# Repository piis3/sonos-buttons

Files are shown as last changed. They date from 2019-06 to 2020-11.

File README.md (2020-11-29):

This is a hobby project for controlling a sonos player using an ESP32 board and a button pad. I got the idea for the 
project while working in my garage and having gloves on or dirty hands and not wanting to mess with my phone to control the 
sonos player in there. Obviously the lazy thing would have been to get a voice assistant in there, but what fun is that?

I wanted something that I could place anywhere in the garage. Being able to run from battery (low power) and WiFi were 
important considerations. I was clearly looking for a fun project here, otherwise I probably would have gone with some 
AWS button concoction, or perhaps gone with one of the commercially available sonos remote control options.

So I wound up going with a handful of stuff from Sparkfun:
- [ESP32 Thing](https://www.sparkfun.com/products/13907)
- [2x2 Button Pad](https://www.sparkfun.com/products/9277)
- [Buttons](https://www.sparkfun.com/products/7836)
- [Buttons Bezel](https://www.sparkfun.com/products/8746)
- [Diodes](https://www.sparkfun.com/products/8588)

The ESP32 fit the bill for the project since it has a ridiculously low power draw when it's in sleep, has WiFi 
built in and the sparkfun board comes with a LIPO battery charger on it.

## Software
I had initially used the Sonos public control API, which goes through Sonos' servers to control your local sonos
player. After getting this all working I found the latency period to be less than ideal. Sonos also
had a multi day service outage while I was wrapping up work on that version. I settled on using the local network UPnP based 
API that the official sonos applications use. Much of the detail on this came from [SoCo](https://github.com/SoCo/SoCo), so 
thanks for that!

Since my hardware design has four buttons, the software supports four opertations:
- Play/Pause
- Next track
- Volume up
- Volume Down

If you want to use this project yourself, you'll need to first find the UID of the sonos player that you want to control. 
For this I recommend using the [SoCo](https://github.com/SoCo/SoCo) library. Once you've got it installed locally:

```
>>> import soco
>>> [zone.uid for zone in soco.discover() if zone.player_name == 'Garage']
['RINCON_XXXXXXXXXXXX']
```

Set the SONOS_UID constant in `sonos_buttons.cpp` to the sonos player UID you want to control and while you're there set the
SSID and PASSWORD macros to your WiFi credentials..

### Building

You'll need an ESP32 development environment setup: see [these instructions](https://docs.espressif.com/projects/esp-idf/en/v3.2.3/get-started/index.html) and you'll need the [ULP Toolchain](https://docs.espressif.com/projects/esp-idf/en/v3.2.3/api-guides/ulp.html#installing-the-toolchain) too. 
Because the esp-arduino module currently requires the v3.2 branch of esp-IDF, you'll need to stick with that version for compiling. 
It looks like the 4.0 branch completely changed how builds work so this project would likely need some updates too.

Once you have the environment setup, run `make menuconfig` and set the default serial port your ESP32 board appears as. This is under the "Serial flasher config" menu item. There's a ton of other options, but that's the only one you need to change.

To flash run `make flash` and then to see serial output run `make monitor`. This will build all of the FreeRTOS stuff too, which is a lot, so make's `-j` argument could be helpful here to use multiple processors.

### Implementation

Since power is a concern here, I wanted to make use of the deep sleep feature of the ESP32 SOC. This allows it to go into a
state that draws *micro*amps of current while still being able to respond to external stimuli. See [the ESP32 sleep docs](https://docs.espressif.com/projects/esp-idf/en/latest/api-reference/system/sleep_modes.html) for details on that.

After waking up from a deep sleep the ESP32 has to rejoin wifi, which usually takes a couple of seconds, so one of the hardest things
was to get it to remember what button was pressed to wake it up from deep sleep. I didn't have a lot of luck with the built-in 
touchpad, or GPIO (ext1) based wakeup solutions. The ext1 stuff kept going into sleep/wake loops, and the touchpad wakeups 
wouldn't report the correct GPIO input for the wakeup source. 

The ESP32 supports wakeup events from a Ultra Low Power (ULP) processor, which is a minimal extra processor that can run some limited code and can wakeup the main processor while
sharing memory with it. When this ULP processor is running and the main processor is in deep sleep, the board supposedly draws current in the 100 microamp
range, so it should still last a very long time on a 1000mah battery. An important point is that during deep sleep, most of main
memory is powered off.  When it wakes up it is effectively like a reboot but the so-called RTC memory is still active. The 
main program can store stuff in this memory (which is 16K I think) and the ULP processor can use an 8K subset of this
which is shared with the main program. 
There isn't a C compiler for the ULP processor, so that part has to be written in assembly with a rather limited 
[instruction set](https://docs.espressif.com/projects/esp-idf/en/latest/api-guides/ulp_instruction_set.html). The ULP program 
lifecycle is a little strange. It's intended to run periodically, woken up by a configurable timer internal to the SOC. In my
case I have it running every 100 milliseconds and it will check to see if any buttons are pressed. If it detects a button press
it will write the button that was pressed into the shared RTC memory and wakeup the main processor(s). If not, it will halt and be restarted by the timer.

On boot the main application does the following:
- Initialize the GPIO pins for controlling the button LEDs and button readers
- Start a FreeRTOS task for controlling the LEDs based on a global variable. This way it can handle keeping the LEDS operational while the CPU is blocked in IO. How cool is it that a tiny computer like this supports real multitasking?
- If we're not waking from sleep, do a cute blinky dance to show off
- If we are waking from sleep, check if the ULP program stashed a button press to be acted on in the first button input loop
- Join wifi and if that fails, do some angry blinking.
- Look in the [Preferences](https://github.com/espressif/arduino-esp32/tree/master/libraries/Preferences) stored on the SOC's flash for the Sonos player's IP address 
- If we don't know the IP address, perform Sonos discovery to find it
- Enter a loop to check for button inputs.
- If a button input occurs, light up the button LED for the duration of the association operation for user feedback and perform that operation.
- After roughly 30 seconds of no button presses (didn't want to introduce a clock, so just based on loop counting hueristics), prepare for deep sleep

Deep Sleep preparation entails:
- Turn off wifi
- Setup RTC IO for the button GPIO inputs and outputs used for the buttons.
- Configure wakeup from ULP sources
- Set the ULP processor timer to run the ULP program 100ms after it halts
- Start the ULP Program
- Enter deep sleep

The ULP Program uses essentially the same mechanism as the main processor code for detecting button proesses so the following mostly applies to both. There is one pin for each button plus a single "reader" pin, details of which are described in the hardware section.
- Configure the reader pin for input only, with the pullup resistor enabled.
- Set the four button pins to HIGH
- Loop over each button pin
    - Set the button pin to LOW
    - Wait a short time
    - Read from the reader pin
    - If the reader pin reads as LOW, then we increment a bounce counter for the button pin, if it's HIGH then we set the bounce counter to 0
    - Set the button pin back to HIGH
    - If the bounce counter for a button reaches 3, consider it a button press.
- If a button is pressed:
    - Write the pressed button into a variable in memory shared between the ULP and the main processors.
    - Wakeup the main processor
    - Disable the ULP wakeup timer so it doesn't keep running with the main processor is running
    - Halt the ULP program

## Hardware

The hardware bits involved here beyond the ESP32 board are a 2x2 button breakout board from sparkfun, along with the associated 
silicon buttons and some little plastic bits to hold everything together. The breakout board has places for full RGB LEDs to
go under each button but I went with simple blue LEDS. These LEDS are meant to provide feedback when the button is pressed. 
After the button press is registered, the LED is lit until the operation associated with it is completed. 
These LEDS are also used all together during startup with a brief flash to indicate successfully joining the wifi network, or 
a series of angry flashes if joining the wifi network failed. 

The button breakout board also has holes for diodes to prevent signals bleeding between rows when doing matrix scanning of the 
button array. I'm not great with electronics stuff, but I don't think this is neccessary with a 2x2 grid where each button has it's own input anyway and is only needed for 4x4 grids. I dutifully soldered them on anyway.

The button side of things is wired up with the switch ground terminals on the breakout board, wired to pins 12, 14, 27 and 26.
The reader pin on the buttons is wired to the switch terminal on the breakout board and GPIO 33 on the ESP32.
You can change this around in the code, but for the ULP bit to work the GPIO pins for the buttons (not LEDS) MUST be 
available from the RTC controller. See section 4.11, RTC_MUX Pin List, on page 57 of the [ESP 32 Technical Reference Manual](https://www.espressif.com/sites/default/files/documentation/esp32_technical_reference_manual_en.pdf).

The LED side of things is wired up to GPIO pins 25, 4, 5, and 18 in the same order with the buttons listed above. These are wired
to the LED GND terminals on the breakout baord. GPIO 32 is used to power these in the `ledLoop()` function and is wired to the
Blue LED terminal on the breakout board. The LED pins were chosen to also be compatible with the Sparkfun WROOM dev board as well.

## Results

I eventually wound up rebuilding this with the [SparkFun Thing Plus](https://www.sparkfun.com/products/15663) and designed a 3d printed case for it.
The case design is in `case/Sonos Button Case.stl`. It's designed to fit the Thing Plus and SparkFun's 2000mah LIPO battery and has places for M2.5 nuts and hex standoffs to hold everything together.
After using this for a while, I can report that it works pretty well. The battery life seems to be about three to four weeks and it is indeed useful when working on projects in the garage. 

There are a few issues. Sometimes it fails to join the wifi, or takes a while to do so. Based on experiences with other projects, I think this might be remedied 
by upgrading to the latest ESP IDF, but that will require re-writing it to use the standard IDF APIs rather than the arduino wrapper.  

## Pictures

### Rebuild with case
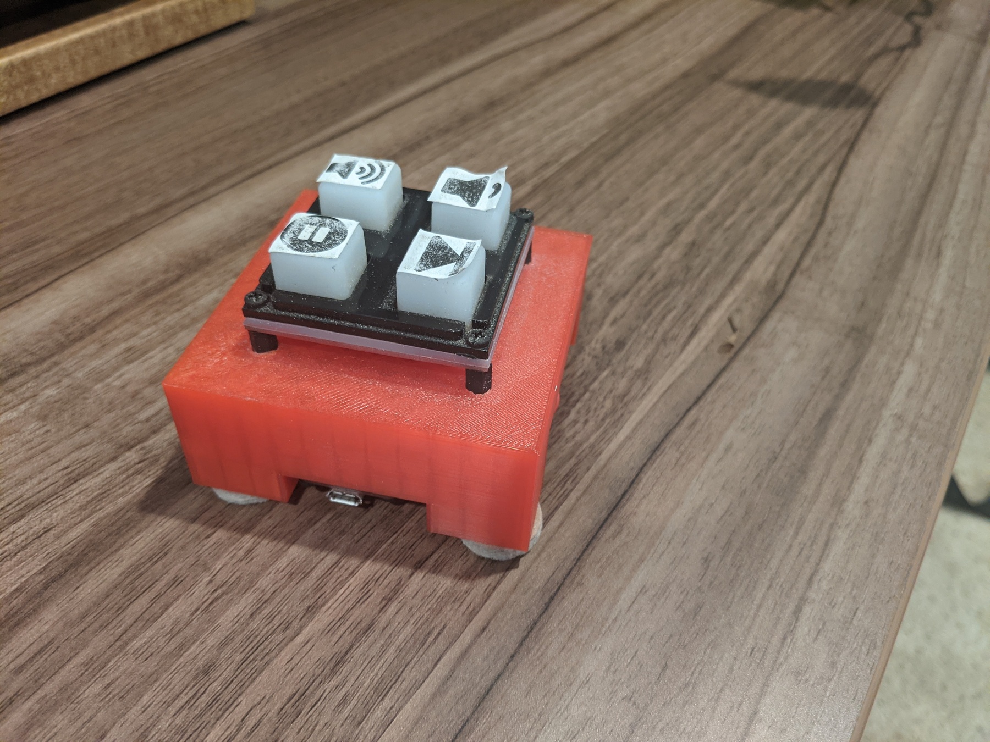
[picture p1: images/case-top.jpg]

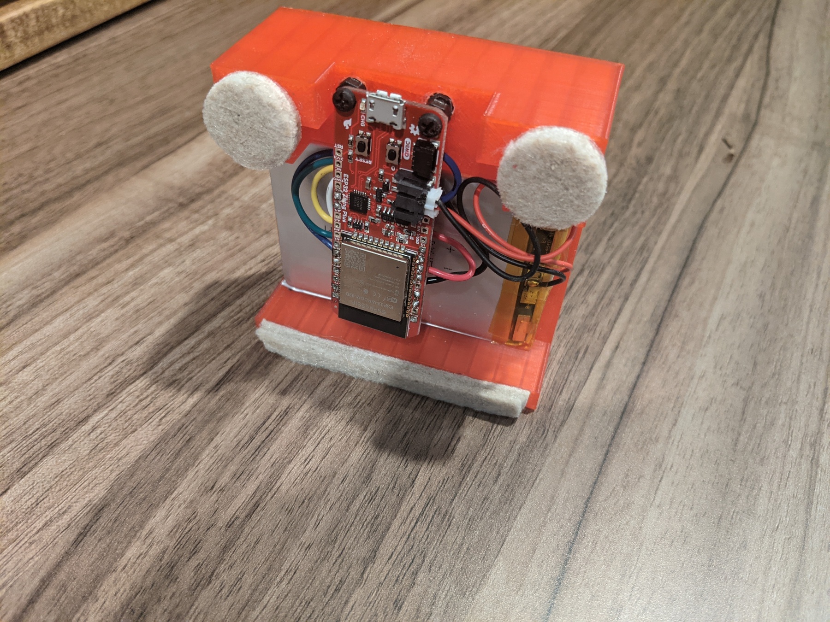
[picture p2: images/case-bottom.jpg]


### Full Project
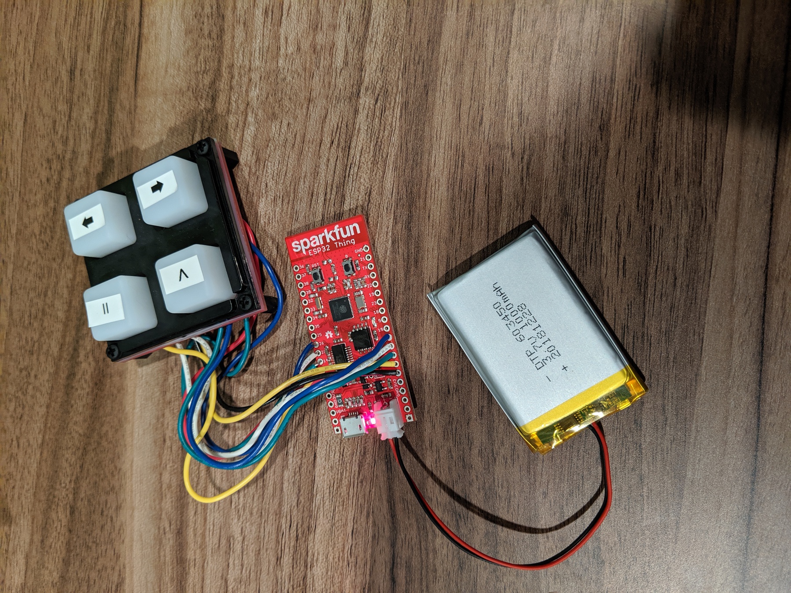
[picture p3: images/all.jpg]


### Breakout board front
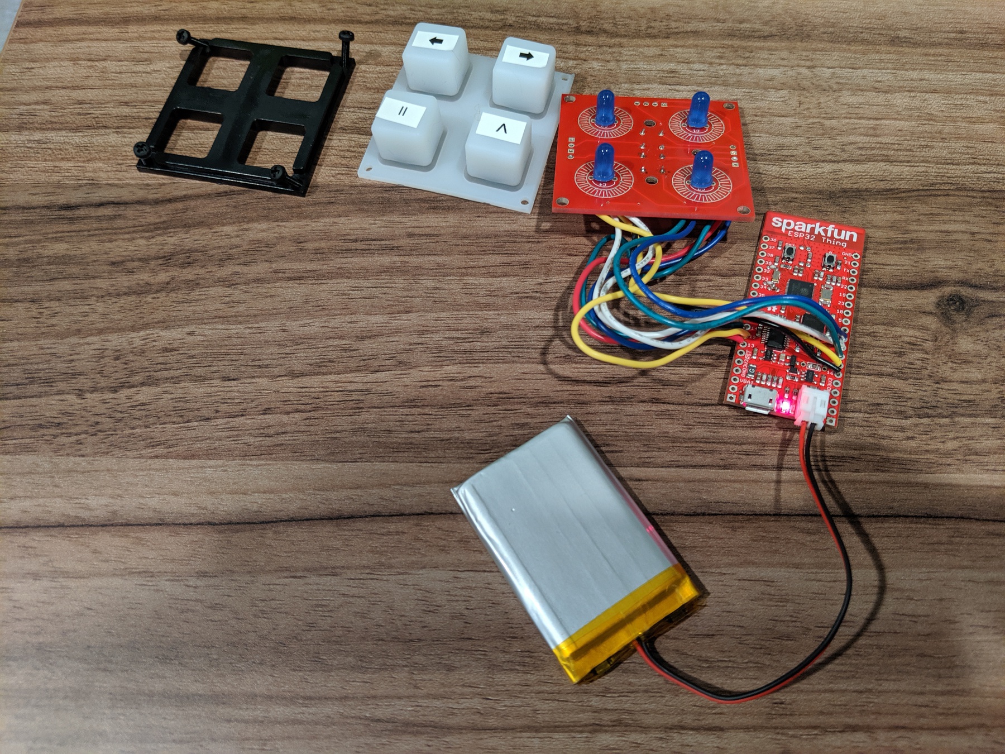
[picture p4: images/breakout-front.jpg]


### Breakout board back
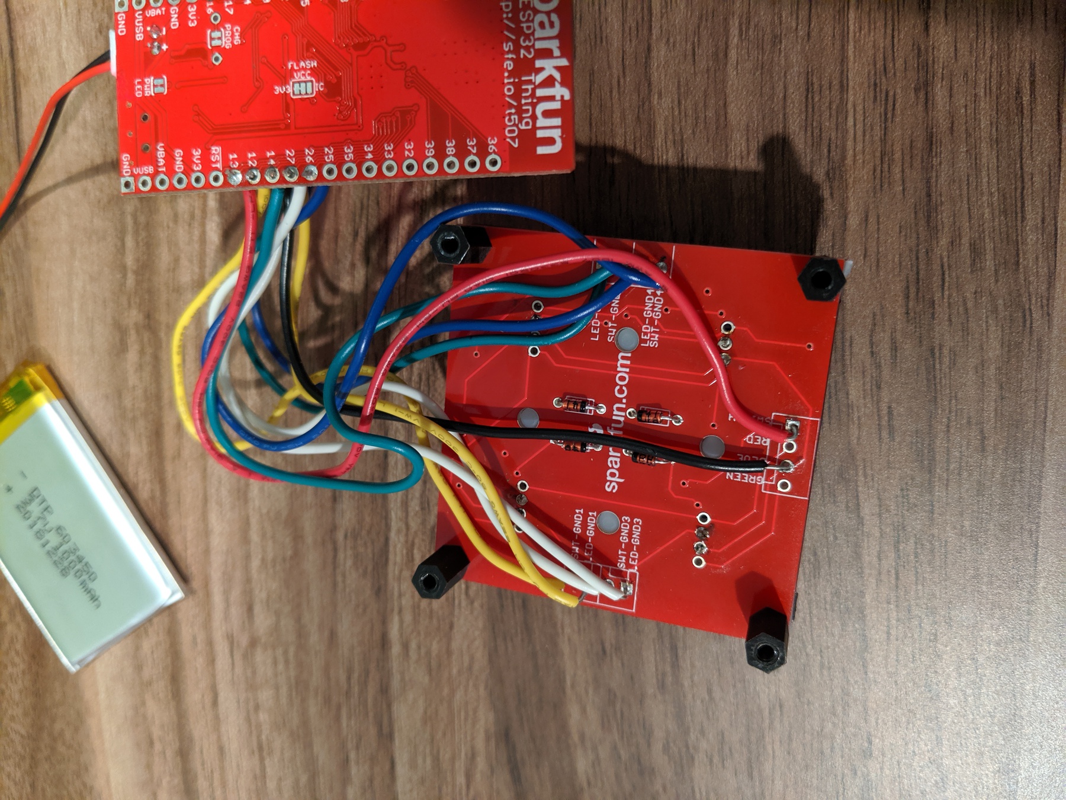
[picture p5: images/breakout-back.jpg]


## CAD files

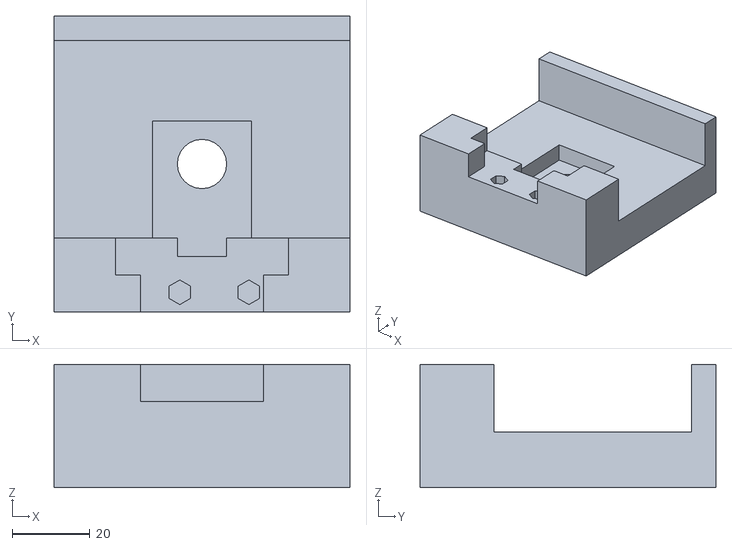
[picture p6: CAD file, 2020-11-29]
case/Sonos Button Case.stl
76.2 x 76.2 x 31.7

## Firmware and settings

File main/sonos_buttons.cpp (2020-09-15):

/******************************************************************************
 * Sonos button control.
 * ESP32 project to control a sonos player with some buttons
 ******************************************************************************/    
#include <Arduino.h>
#include <WiFi.h>
#include <WiFiMulti.h>
#include <HTTPClient.h>
#include <AsyncUDP.h>
#include <string.h>
#include <Preferences.h>
#include <esp_sleep.h>
#include <esp_wifi.h>
#include <driver/touch_pad.h>
#include <driver/rtc_io.h>
#include "ulp_main.h"
#include "sonos.h"
#include <esp32/ulp.h>
#include "config.h"

#define LOG_LOCAL_LEVEL ESP_LOG_VERBOSE
#include "esp_log.h"

//config variables
#define NUM_BTN_COLUMNS (4)
#define NUM_BTN_ROWS (1)
#define NUM_LED_COLUMNS (4)
#define NUM_LED_ROWS (1)

#define MAX_DEBOUNCE (3)

// This is roughly 30 seconds with the various delays + scanning time
#define IDLE_LOOPS_SLEEPY 4500

static const gpio_num_t btncolumnpins[NUM_BTN_COLUMNS] = {GPIO_NUM_12, GPIO_NUM_14, GPIO_NUM_27, GPIO_NUM_26};
static const gpio_num_t btnrowpins[NUM_BTN_ROWS]       = {GPIO_NUM_33};

static const gpio_num_t ledcolumnpins[NUM_LED_COLUMNS] = {GPIO_NUM_25, GPIO_NUM_4, GPIO_NUM_5, GPIO_NUM_18};
static const gpio_num_t colorpins[NUM_LED_ROWS]        = {GPIO_NUM_32};

extern const uint8_t bin_start[] asm("_binary_ulp_main_bin_start");
extern const uint8_t bin_end[]   asm("_binary_ulp_main_bin_end");

static int8_t debounce_count[NUM_BTN_COLUMNS][NUM_BTN_ROWS];
static const char* TAG = "SonosButtons";

// bit field representing the buttons activated on the last scan loop
static uint8_t buttons_released = 0;
// bit field representing the buttons activated that caused us to wakeup
uint8_t sleep_buttons = 0;

static uint8_t LEDS_lit = 0;
static IPAddress targetSonos;

// Store the base station mac address and channel in RTC memory so we can re-connect more quickly
static RTC_DATA_ATTR struct {
    uint8_t bssid [6];
    uint16_t channel; // Make this 16 bites to align on the 32 bit boundary
} wifi_cache;

static RTC_DATA_ATTR uint32_t wifi_cache_checksum;

void clearWifiCache() {
    wifi_cache_checksum = 1;
    for (uint32_t i = 0; i < sizeof(wifi_cache.bssid); i++) {
        wifi_cache.bssid[i] = 0xFF;
    }
    wifi_cache.channel = 0;
}

bool checkWifiCache() {
    uint32_t readSum = 0;
    uint32_t *p = (uint32_t *) wifi_cache.bssid;
    for (uint32_t i = 0; i < sizeof(wifi_cache) / 4; i++) {
        readSum += p[i];
    }

    bool hasRealData = false;
    for (uint32_t i = 0; i < sizeof(wifi_cache.bssid); i++) {
        hasRealData |= (wifi_cache.bssid[i] != 0 && wifi_cache.bssid[i] != 0xFF);
    }
    if (readSum == wifi_cache_checksum && hasRealData) {
        ESP_LOGD(TAG, "Good Wifi cache checksum %d, %X:%X:%X:%X:%X:%X, channel %d\n",
            readSum,
            wifi_cache.bssid[0],
            wifi_cache.bssid[1],
            wifi_cache.bssid[2],
            wifi_cache.bssid[3],
            wifi_cache.bssid[4],
            wifi_cache.bssid[5],
            wifi_cache.channel
        );
        return true;
    } else {
        ESP_LOGI(TAG, "Bad wifi cache checksum, clearing storage");
        clearWifiCache();
        return false;
    }
}

void storeWifiCache() {
    uint8_t *bssid = WiFi.BSSID();
    memcpy(wifi_cache.bssid, bssid, sizeof(wifi_cache.bssid));
    wifi_cache.channel = WiFi.channel();

    uint32_t checkSum = 0;
    uint32_t *p = (uint32_t *) wifi_cache.bssid;

    for (uint32_t i = 0; i < sizeof(wifi_cache) / 4; i++) {
        checkSum += p[i];
    }

    wifi_cache_checksum = checkSum;
}


static void setuppins() {
    uint8_t i, j;

    // button columns
    for (i = 0; i < NUM_BTN_COLUMNS; i++) {
        rtc_gpio_deinit(btncolumnpins[i]);
        pinMode(btncolumnpins[i], OUTPUT);
        digitalWrite(btncolumnpins[i], HIGH);
    }

    for (i = 0; i < NUM_LED_COLUMNS; i++) {
        pinMode(ledcolumnpins[i], OUTPUT);
        digitalWrite(ledcolumnpins[i], HIGH);
    }

    // button row input lines
    for (i = 0; i < NUM_BTN_ROWS; i++) {
        rtc_gpio_deinit(btnrowpins[i]);
        pinMode(btnrowpins[i], INPUT_PULLUP);
    }

    // LED drive lines
    for (i = 0; i < NUM_LED_ROWS; i++) {
        pinMode(colorpins[i], OUTPUT);
        digitalWrite(colorpins[i], LOW);
    }

    // Initialize the debounce counter array
    for (i = 0; i < NUM_BTN_COLUMNS; i++) {
        for (j = 0; j < NUM_BTN_ROWS; j++)  {
            debounce_count[i][j] = 0;
        }
    }

    pinMode(5, OUTPUT);
    digitalWrite(5, LOW);
    LEDS_lit = 0;
}

// Button detection, adapted from the sparkfun hookup guide at https://learn.sparkfun.com/tutorials/button-pad-hookup-guide
static void scan() {
    buttons_released = 0;
    static uint8_t current = 0;
    uint8_t val;
    uint8_t j;

    // Select current columns
    digitalWrite(btncolumnpins[current], LOW);
    // pause a moment
    delay(1);

    // Read the button inputs
    for (j = 0; j < NUM_BTN_ROWS; j++) {
        val = digitalRead(btnrowpins[j]);

        if (val == LOW) {
            // active low: val is low when btn is pressed
            if (debounce_count[current][j] < MAX_DEBOUNCE) {
                debounce_count[current][j]++;
            }
        }
        else {
            // otherwise, button is released
            if (debounce_count[current][j] > 0) {
                debounce_count[current][j]--;

                if (debounce_count[current][j] == 0 ) {
                    uint8_t released = (current * NUM_BTN_ROWS) + j;
                    bitSet(buttons_released, released);
                    // Turn on the LED while we're working
                    bitSet(LEDS_lit, released);
                }
            }
        }
    }// for j = 0 to 3;

    delay(1);
    digitalWrite(btncolumnpins[current], HIGH);

    current++;
    if (current >= NUM_BTN_COLUMNS) {
        current = 0;
    }
}

void ledLoop( void * args ) {
  
    uint8_t i;
    static uint8_t current = 0;

    for ( ;; ) {
        for (current = 0; current < NUM_BTN_COLUMNS; current++) {
            delay(1);
            // output LED row values
            for (i = 0; i < NUM_LED_ROWS; i++) {
                digitalWrite(colorpins[i], LOW);
                if (bitRead(LEDS_lit, (current * NUM_BTN_ROWS) + i)) {
                    digitalWrite(ledcolumnpins[current], HIGH);
                }
            }
        }
        delay(10); 
        for (current = 0; current < NUM_BTN_COLUMNS; current++) {
            digitalWrite(ledcolumnpins[current], LOW);
            for (i = 0; i < NUM_LED_ROWS; i++) {
                digitalWrite(colorpins[i], HIGH);
            }
        }
        if (LEDS_lit == 0) {
            delay(25);
        } 
    }
}

void blinkAll(uint8_t times, int waitTime) {
    uint8_t startVal = LEDS_lit;
    for (uint8_t i = 0; i < times; i++) {
       delay(waitTime);
       LEDS_lit = 255;
       delay(waitTime);
       LEDS_lit = startVal;
    }
}

boolean didJustWake() {
    esp_sleep_wakeup_cause_t wakeup_reason;
    wakeup_reason = esp_sleep_get_wakeup_cause();

    boolean wokeUp = false;
    if (wakeup_reason == ESP_SLEEP_WAKEUP_ULP) {
        ESP_LOGI(TAG, "Woke up from sleep (ULP)");
        sleep_buttons = ulp_wake_gpio_bit & 0xFF;
        ESP_LOGD(TAG, "GPIO pressed was %d\n", ulp_wake_gpio_bit & 0xFF);
        ulp_wake_gpio_bit = 0;
        LEDS_lit = sleep_buttons;
        wokeUp = true;
    } else {
        ESP_LOGW(TAG, "Wakeup was not caused by deep sleep: %d\n",wakeup_reason); 
        sleep_buttons = 0;
    }

    return wokeUp;
}

boolean connectWifi() {
    WiFi.mode(WIFI_STA);
    bool wasCached = checkWifiCache();
    if (wasCached) {
        // Connect using a cached bssid and channel
        ESP_LOGD(TAG, "Connecting using cached wifi config");
        WiFi.begin(SSID, PASSWORD, wifi_cache.channel, wifi_cache.bssid, true);
    } else {
        ESP_LOGD(TAG, "Connecting to without cached wifi config");
        WiFi.begin(SSID, PASSWORD);
    }

    ESP_LOGD(TAG, "Waiting for WiFi to connect...");
    uint8_t wifiTries = 0;
    wl_status_t status = WiFi.status();
    while (status != WL_CONNECTED && status != WL_CONNECT_FAILED && wifiTries < 50) {
        delay(50);
        status = WiFi.status();
        wifiTries += 1;
    }

    if (! WiFi.isConnected() ) {
        if (wasCached) {
            clearWifiCache();
            return connectWifi();
        } else {
            ESP_LOGE(TAG, "WiFi connect failed, restarting");
            delay(1000);
            blinkAll(10, 100);
            ESP.restart();
        }
    }
    ESP_LOGI(TAG, "WiFi connect succeeded");
    return true;
}

void setup() {
    // setup hardware
    Serial.begin(115200);
    setuppins();

    xTaskCreatePinnedToCore(
        ledLoop,
        "LEDLoop",
        1024,
        NULL,
        2,
        NULL,
        1
    );
    boolean woke = didJustWake();

    if (!woke) {
        LEDS_lit = 1;
        delay(250);
        LEDS_lit = 3;
        delay(250);
        LEDS_lit = 7;
        delay(250);
        LEDS_lit = 15;
        delay(250);
        LEDS_lit = 0;
    }
    connectWifi();

    LEDS_lit = 255;
    delay(100);
    LEDS_lit = 0;

    Preferences prefs;
    prefs.begin("sonos", true);
    String addr = prefs.getString("playerAddress", "");
    String prefUid = prefs.getString("playerUid", "");
    prefs.end();
    // If the configured sonos UID is different than what we stored, we need to forget our cached IP
    if (prefUid != String(SONOS_UID)) {
        prefs.begin("sonos", false);
        prefs.remove("playerAddress");
        prefs.end();
        addr = String("");
    }
    if (addr.length() > 0) {
        IPAddress ip;
        ip.fromString(addr.c_str());
        if (ip) {
            targetSonos = ip;
            ESP_LOGI(TAG, "Using cached sonos IP %s", targetSonos.toString().c_str());
        }
    }
    if (!targetSonos) {
        targetSonos = discoverSonos(std::string(SONOS_UID));
    }
}

void napTime() {
    if (WiFi.isConnected()) {
        storeWifiCache();
    }
    esp_wifi_stop();
    ESP_LOGD(TAG, "Starting ULP processor");

    for (uint8_t i = 0; i < NUM_BTN_COLUMNS; i++) {
        rtc_gpio_init(btncolumnpins[i]);
        rtc_gpio_set_direction(btncolumnpins[i], RTC_GPIO_MODE_OUTPUT_ONLY);
        rtc_gpio_pulldown_dis(btncolumnpins[i]);
        rtc_gpio_pullup_dis(btncolumnpins[i]);
        rtc_gpio_hold_dis(btncolumnpins[i]);
    }
  
    for (uint8_t i = 0; i < NUM_BTN_ROWS; i++) {
        rtc_gpio_init(btnrowpins[i]);
        rtc_gpio_set_direction(btnrowpins[i], RTC_GPIO_MODE_INPUT_ONLY);
        rtc_gpio_pulldown_dis(btnrowpins[i]);
        rtc_gpio_pullup_en(btnrowpins[i]);
        rtc_gpio_hold_en(btnrowpins[i]);
    }

    esp_sleep_enable_ulp_wakeup();
    ESP_ERROR_CHECK( ulp_load_binary(
        0 /* load address, set to 0 when using default linker scripts */,
        bin_start,
        (bin_end - bin_start) / sizeof(uint32_t)) 
    );
    // Reset the ULP wake bit to zero in case an intervening run set it to a button and it wasn't cleaned up
    ulp_wake_gpio_bit = 0;
    ESP_LOGI(TAG, "Going to sleep now");
    ESP_ERROR_CHECK( ulp_run(&ulp_scan_btns - RTC_SLOW_MEM) );
    // Wakeup the ULP processor every 100 ms to check for button presses
    ESP_ERROR_CHECK( ulp_set_wakeup_period(0, 100000) );
    esp_deep_sleep_start();
}

// Second layer of sonos operation wrapper to handle the rediscovery logic
void doSonos(int (*operation)(HTTPClient *http, IPAddress targetSonos)) {
    if (!targetSonos) {
        targetSonos = discoverSonos(std::string(SONOS_UID));
    }
    if (!targetSonos) {
        ESP_LOGE(TAG, "Couldn't find the right sonos, bailing");
        return;
    }

    int error = sonosOperation(operation, targetSonos);
    if (error) {
        // try rediscovering
        targetSonos = discoverSonos(std::string(SONOS_UID));
    }
}

void loop() {
    static int idleLoopCount = 0;

    int handle_buttons = buttons_released | sleep_buttons;
    // Clear the sleep_buttons variable so we only handle it once
    sleep_buttons = 0;
    scan();
    if (handle_buttons != 0) {
        idleLoopCount = 0;
        if (bitRead(handle_buttons, 0)) {
            ESP_LOGI(TAG, "Sending play/pause");
            doSonos(sonosPlay);
            bitClear(LEDS_lit, 0);
        } else if (bitRead(handle_buttons, 1)) { 
            ESP_LOGI(TAG, "Sending next");
            doSonos(sonosNext);
            bitClear(LEDS_lit, 1);
        } else if (bitRead(handle_buttons, 2)) {
            ESP_LOGI(TAG, "Sending volume up");
            doSonos(volumeUp);
            bitClear(LEDS_lit, 2);
        } else if (bitRead(handle_buttons, 3)) {
            ESP_LOGI(TAG, "Sending volume down");
            doSonos(volumeDown);
            bitClear(LEDS_lit, 3);
        } else {
            ESP_LOGE(TAG, "Not implemented");
            delay(1000);
            LEDS_lit = 0;
        }
    } else {
        delay(5);
        idleLoopCount += 1;
        if (idleLoopCount >= IDLE_LOOPS_SLEEPY) {
            idleLoopCount = 0;
            napTime();
        }
    }
}

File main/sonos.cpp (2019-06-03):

#include <Arduino.h>
#include <HTTPClient.h>
#include <AsyncUDP.h>
#include <AsyncUDP.h>
#include <string.h>
#include <expat.h>
#include <Preferences.h>
#include "sonos.h"

static const char* PLAYER_SEARCH = "M-SEARCH * HTTP/1.1\r\n"
    "HOST: 239.255.255.250:1900\r\n"
    "MAN: \"ssdp:discover\"\r\n"
    "MX: 1\r\n"
    "ST: urn:schemas-upnp-org:device:ZonePlayer:1\r\n";

static std::string soapCall(std::string operation) {
    return "<?xml version=\"1.0\"?>"  
        "<s:Envelope s:encodingStyle=\"http://schemas.xmlsoap.org/soap/encoding/\" xmlns:s=\"http://schemas.xmlsoap.org/soap/envelope/\">" 
          "<s:Body>"  
            "<u:" + operation + " xmlns:u=\"urn:schemas-upnp-org:service:AVTransport:1\">" 
              "<InstanceID>0</InstanceID>"  
              "<Speed>1</Speed>"  
            "</u:" + operation + ">" 
          "</s:Body>"  
        "</s:Envelope>";
}

static const std::string GET_VOLUME_CALL = "<?xml version=\"1.0\"?>"
    "<s:Envelope xmlns:s=\"http://schemas.xmlsoap.org/soap/envelope/\" s:encodingStyle=\"http://schemas.xmlsoap.org/soap/encoding/\">"
        "<s:Body>"
            "<u:GetVolume xmlns:u=\"urn:schemas-upnp-org:service:RenderingControl:1\">"
                "<InstanceID>0</InstanceID>"
                "<Channel>Master</Channel>"
            "</u:GetVolume>"
        "</s:Body>"
    "</s:Envelope>";

static std::string changeVolumeCall(int volume) {
    return "<?xml version=\"1.0\"?>"
    "<s:Envelope xmlns:s=\"http://schemas.xmlsoap.org/soap/envelope/\" s:encodingStyle=\"http://schemas.xmlsoap.org/soap/encoding/\">"
        "<s:Body>"
            "<u:SetVolume xmlns:u=\"urn:schemas-upnp-org:service:RenderingControl:1\">"
                "<InstanceID>0</InstanceID>"
                "<Channel>Master</Channel>"
                "<DesiredVolume>" + std::string(String(volume).c_str()) + "</DesiredVolume>"
            "</u:GetVolume>"
        "</s:Body>"
    "</s:Envelope>";
}

std::string tagValue(std::string xmlData, std::string tagName) {

    typedef struct state {
        std::string captured;
        boolean capturing;
        std::string tagName;
    } ParseState;

    std::string captured;

    ParseState state = {
        captured,
        false,
        tagName
    };

    XML_StartElementHandler start = [](void *myState, const char *el, const char **attr) {
        ParseState *d = (ParseState*) myState;
        if (strncmp(el, d->tagName.c_str(), d->tagName.length()) == 0) {
            d->capturing = true;
        }
    };
    XML_EndElementHandler end = [](void *myState, const char *el) {
        ParseState *d = (ParseState*) myState;
        d->capturing = false;
    };
    XML_CharacterDataHandler charData = [](void *myState, const char *s, int len) {
        ParseState *d = (ParseState*) myState;
        if (d->capturing) {
            d->captured += std::string(s, len);
        }
    };
    XML_Parser p = XML_ParserCreate(NULL);
    if (! p) {
        Serial.println("Couldn't allocate parser");
    } else {
        XML_SetUserData(p, &state);
        XML_SetElementHandler(p, start, end);
        XML_SetCharacterDataHandler(p, charData);
        XML_Parse(p, xmlData.c_str(), xmlData.length(), true);
        XML_ParserFree(p);
    }
    return state.captured;

}

// Find the Location attribute for the player specified by uid
std::string filterDeviceLocation(std::string xmlData, std::string targetUid) {
    typedef struct state {
        std::string location;
        std::string targetUid;
    } ParseState;

    std::string location;

    ParseState state = {
        location,
        targetUid
    };

    XML_StartElementHandler start = [](void *myState, const char *el, const char **attr) {
        ParseState *state = (ParseState *) myState;
        // 15 is ZoneGroupMember length
        if (strncmp(el, "ZoneGroupMember", 15) == 0) {
            std::string loc;
            std::string uid;

            for (int i = 0;; i += 2) {
                const char *key = attr[i];
                if (key == NULL) {
                    break;
                }
                const char *value = attr[i + 1];
                if (value == NULL) {
                    break;
                }

                if (strncmp(key, "UUID", 4) == 0) {
                    uid = std::string(value);
                } else if (strncmp(key, "Location", 8) == 0) {
                    loc = std::string(value);
                }
            }
            
            if (loc.length() > 0 && (uid == state->targetUid)) {
                state->location += loc;
            }
        }
    };

    XML_Parser p = XML_ParserCreate(NULL);
    if (! p) {
        Serial.println("Couldn't allocate parser");
    } else {
        XML_SetUserData(p, &state);
        XML_SetElementHandler(p, start, NULL);
        XML_Parse(p, xmlData.c_str(), xmlData.length(), true);
        XML_ParserFree(p);
    }

    return state.location;
}


/**
 * Given any sonos' address, ask it for the zone topology to find the right sonos
 */
IPAddress zoneTopology(HTTPClient *http, std::string host, std::string targetUid) {
    auto postBody = soapCall("GetZoneGroupState");

    IPAddress ipaddr;

    if (http->begin(host.c_str(), SONOS_PORT, "/ZoneGroupTopology/Control")) {
        http->addHeader("Content-Type", "text/xml; charset=\"utf-8\"");
        http->addHeader("SOAPACTION", "urn:schemas-upnp-org:service:ZoneGroupTopology:1#GetZoneGroupState");
        int httpCode = http->POST(postBody.c_str());
        if (httpCode == 200) {
            // The body here is an XML doc embedded in the body of another, so just pull out the first one, then run it through the next parser
            std::string innerXml = tagValue(std::string(http->getString().c_str()), "ZoneGroupState");
            std::string locationUrl = filterDeviceLocation(innerXml, targetUid);
            if (locationUrl.length() > 0 && locationUrl.length() > 7) {
                Serial.printf("Found location: %s\n", locationUrl.c_str());

                int pos = locationUrl.find(":", 7);
                if (pos > 0) {
                    ipaddr.fromString(locationUrl.substr(7, pos - 7).c_str());
                }
            }
            if (!ipaddr) {
                Serial.println("Couldn't find location descriptor for sonos");
            }
        } else {
            Serial.printf("Got bad status code getting zone topology %d: %s\n", httpCode, http->getString().c_str());
        }
    }
    return ipaddr;
}
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

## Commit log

2019-06-06 Fix wakeup by other sources performing actions
    A no longer advisable switch statement from debugging was causing
    wakeups due to reasons other than deep sleep to be interpretted as a
    sleep wakeup, along with reading possibly old values of the wake up bits
    variable.
    [sonos_buttons.cpp]
2019-06-07 Disable ULP timer on wakeup
    When I removed the bit disabling the wakeup timer for the ULP processor
    it looks like it wound up causing a race during initialization between
    the main processor seeing the button bits and the ULP processor
    clearing them. So we need to make sure to turn off the ULP processor.
2019-06-30 Improve reconnect time
    Store the wifi channel and bssid that we last connected to in RTC memory
    so that we can reconnect to wifi much more quickly when coming back from
    deep sleep. If we fail to connect to wifi, clear this cache before we
    restart so we'll reconnect and do the full scan
    [sonos_buttons.cpp]
2019-08-31 Fix connect to wifi using cached config
    We need to use a different method signature for connecting to wifi using
    cached configs in order for it to work properly.
    Also update to the latest ESP_IDF version in the 3.x series.
    Move the config for wifi and sonos stuff into it's own file
    [sonos_buttons.cpp]
2020-09-07 Update pins to work with WROOM board
    I switched my dev board to the WROOM board from sparkfun so switch to
    pins that should be compatible with both.
    It looks like I had an old version of the ULP assembly checked in, so
    this one actually works.
2020-09-15 Use GPIO_33 instead of GPIO_13
    GPIO_13 is traditionally hooked up to an LED on dev boards
    so we should avoid using it so we don't blink an LED unnecessarily.
    [sonos_buttons.cpp]
2020-11-29 Add case design and new pictures
    Show off how this actually turned out and include a case design I made
    for it along with some pictures of the end product.
    [Sonos Button Case.stl]
